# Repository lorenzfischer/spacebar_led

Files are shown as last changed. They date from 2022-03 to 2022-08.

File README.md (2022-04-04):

# Swiss Space Bar LED Installation

> Disclaimer: I am heavily re-using code of an existing project called [Audio Reactive LED Strip](https://github.com/scottlawsonbc/audio-reactive-led-strip)
> by [Scott Lawson](https://github.com/scottlawsonbc). See below for the description of the original project. Please 
> have a read through that, as it explains all of the basics around how to run the python code. I currently only use 
> the "Computer + ESP8266" mode which I have extended to support multiple LED strip clients over a server broadcast
> and client registration (see [client_management.py](python/client_management.py) )

This project aims at developing a hybrid LED system that can be used (i) on a fixed location and (ii) on foot 
when moving around. When multiple LED clients are in the same location, the light show will be sychronised, which 
which should look nice at the bar, on bikes, or when walking around.

The basic idea is to have:

2. a series of LED "things" (LED clients) who are all being fed a light show by a
3. server (either one of the clients or a dedicated server machine)

To keep everything "mobile" we need some wireless communication as well as power from a battery.

There are different modes of operations, currently the following 3 are envisioned:

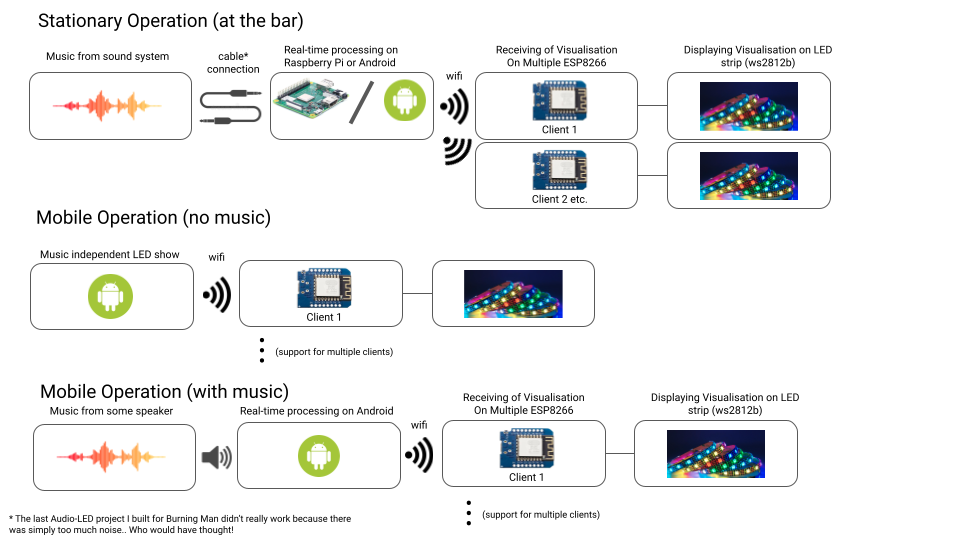
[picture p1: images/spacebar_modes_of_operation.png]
modes of operation


To see whether this is feasible, I have created a demo that is recorded here: https://youtu.be/f2kS4P1rJ0Y
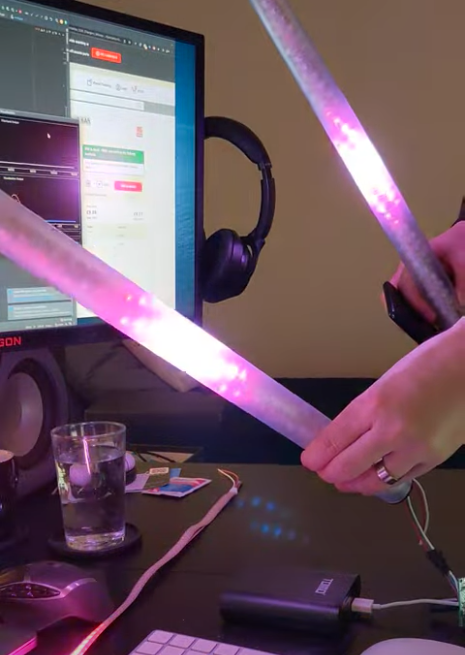
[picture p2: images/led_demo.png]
demo video (https://youtu.be/f2kS4P1rJ0Y)

(click to play)

## ToDo List:

 - [x] Build demo led tube and get others onboard
 - [ ] Brainstorm other/better/larger LED setups (currently we use strips)
   - [ ] Sync with Chef Juke about laser cutting acrylic discs so we could build a tube full of them looking a bit [like this](https://www.youtube.com/watch?v=GtKIkkLkrwU&t=1210s)
 - [ ] Implement different resolutions (currently only 140 LED resolution supported)
 - [ ] Figure out power (battery power)
 - [ ] Figure out charging situation (using charge controller or through removable 18650s?)
 - [ ] Design a handle that can be 3d-printed + easily re-charged overnight
 - [ ] Add status LEDs to circuit and code
 - [ ] Implement dynamic network ports (so we can restart faster) 

## Build of sample tubes

To build the sample tubes, I used ideas that I found in [this video](https://www.youtube.com/watch?v=qnP8-wJVAlI):
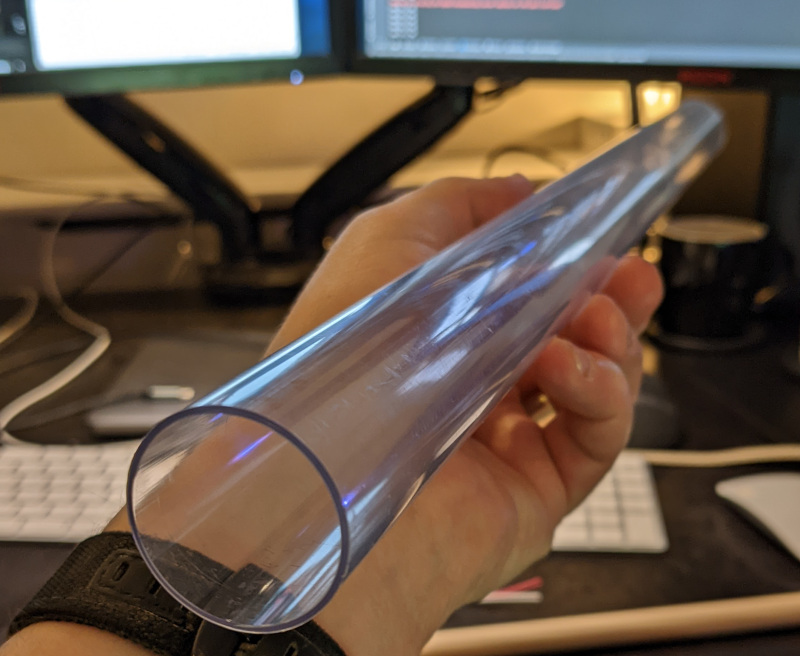
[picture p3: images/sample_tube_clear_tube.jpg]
base tube
1. I used a bunch of acrylic tubes (30mm/32mm inside/outside diameter - clear ones as amazon.co.uk didn't stock anything else) . I sanded them using 600 grit and then 1500 grit sandpaper to get them to diffuse the light.
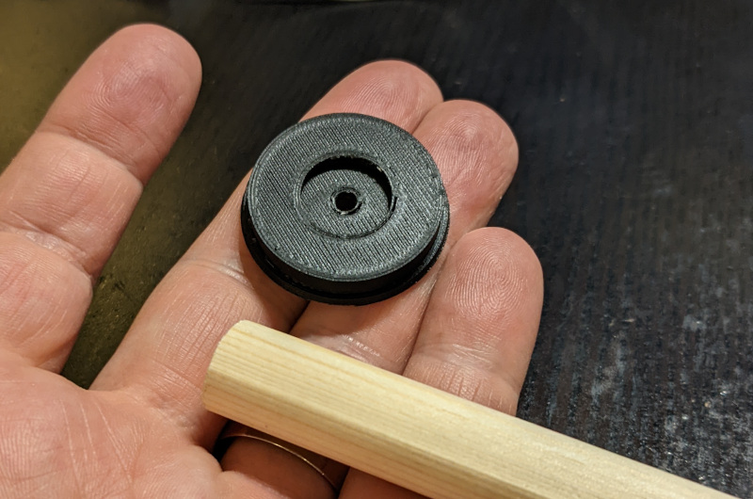
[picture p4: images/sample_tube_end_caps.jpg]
end caps
2. I used 3D printed end caps ([lid.v2.stl](3d_objects/lid.v2.stl) and [lid.v2.with_hole](3d_objects/lid.v2.with_hole.gcode) both in [lid.v2.with_hole.2x.gcode](3d_objects/lid.v2.with_hole.2x.gcode) ready to be printed): 
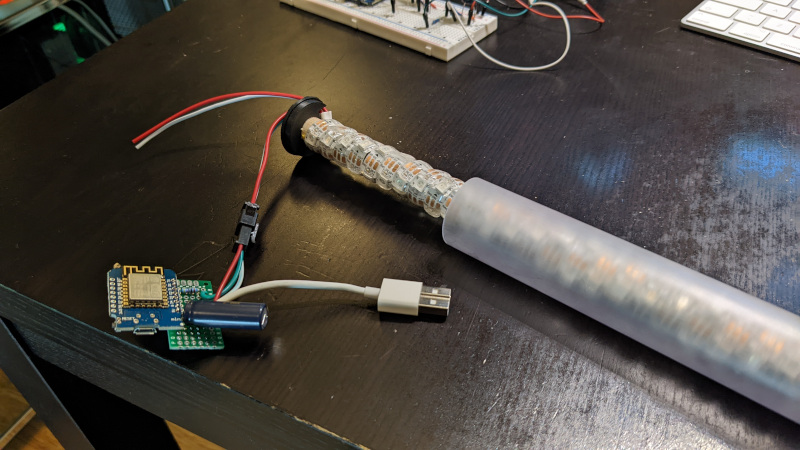
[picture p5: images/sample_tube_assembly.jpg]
tube assembly
3. I then rolled the LED strip around the dowel (superglued each end) and closed the sides (one of the caps has a hole for the cables): 
4. For the circuit I pretty much used the [NeoPixel Wiring Diagram from Adafruit](https://learn.adafruit.com/adafruit-neopixel-uberguide/basic-connections). The only difference that I had is that I used the ESP8266, so the data pin is the RX pin. Currently I power the thing over 5V/Gnd using a USB cable of which I only use the 5V/GND cables (also I didn't have any 1000uF capacitors, so I used 2200uF ones): wiring diagram

## Shopping List
To run one of these tubes you need:
 - a mac or pc running python 3 (2 is not fully supported)
 - a wifi access point in your network
 - (~$5) an ESP8266 (I bought [10 for £25](https://www.amazon.co.uk/gp/product/B08QZ2887K/ref=ppx_yo_dt_b_search_asin_title?ie=UTF8&psc=1))
 - (~$8) an WS2812B LED strip (I used [60 LEDs/m strips from AliExpress](https://www.aliexpress.com/item/4000875413944.html?spm=a2g0o.order_detail.0.0.18b1f19cblbxeD), 5m is enough for two 0.5m tubes)
 - (~5-10) an acrylic/polycarbonate/pet tube (if you find a 30mm/32mm one, you can use the lids from above)
 - a 14mm diameter wooden dowel, same length as the tube (minus 4mm, 2 each side for the cap)
 - two wood screws 3x25mm
 - a 470 Ohms resistor
 - A 1000 uF capacitor

-----

# Original Description: Audio Reactive LED Strip
Real-time LED strip music visualization using Python and the ESP8266 or Raspberry Pi.

block diagram

overview

# Demo (click gif for video)

visualizer demo (https://www.youtube.com/watch?v=HNtM7jH5GXgD)

# Overview
The repository includes everything needed to build an LED strip music visualizer (excluding hardware):

- Python visualization code, which includes code for:
  - Recording audio with a microphone ([microphone.py](python/microphone.py))
  - Digital signal processing ([dsp.py](python/dsp.py))
  - Constructing 1D visualizations ([visualization.py](python/visualization.py))
  - Sending pixel information to the ESP8266 over WiFi ([led.py](python/led.py))
  - Configuration and settings ([config.py](python/config.py))
- Arduino firmware for the ESP8266 ([ws2812_controller_esp8266.ino](arduino/ws2812_controller_esp8266/ws2812_controller_esp8266.ino))

# What do I need to make one?
## Computer + ESP8266
To build a visualizer using a computer and ESP8266, you will need:
- Computer with Python 2.7 or 3.5 ([Anaconda](https://www.anaconda.com/distribution/) is recommended on Windows)
- ESP8266 module with RX1 pin exposed. These modules can be purchased for as little as $5 USD. These modules are known to be compatible, but many others will work too:
  - NodeMCU v3
  - Adafruit HUZZAH
  - Adafruit Feather HUZZAH
- WS2812B LED strip (such as Adafruit Neopixels). These can be purchased for as little as $5-15 USD per meter.
- 5V power supply
- 3.3V-5V level shifter (optional, must be non-inverting)

Limitations when using a computer + ESP8266:
- The communication protocol between the computer and ESP8266 currently supports a maximum of 256 LEDs.

## Standalone Raspberry Pi
You can also build a standalone visualizer using a Raspberry Pi. For this you will need: 
- Raspberry Pi (1, 2, or 3)
- USB audio input device. This could be a USB microphone or a sound card. You just need to find some way of giving the Raspberry Pi audio input.
- WS2812B LED strip (such as Adafruit Neopixels)
- 5V power supply
- 3.3V-5V level shifter (optional)

Limitations when using the Raspberry Pi:
- Raspberry Pi is just fast enough the run the visualization, but it is too slow to run the GUI window as well. It is recommended that you disable the GUI when running the code on the Raspberry Pi.
- The ESP8266 uses a technique called temporal dithering to improve the color depth of the LED strip. Unfortunately the Raspberry Pi lacks this capability.

# Installation for Computer + ESP8266
## Python Dependencies
Visualization code is compatible with Python 2.7 or 3.5. A few Python dependencies must also be installed:
- Numpy
- Scipy (for digital signal processing)
- PyQtGraph (for GUI visualization)
- PyAudio (for recording audio with microphone)

On Windows machines, the use of [Anaconda](https://www.anaconda.com/distribution/) is **highly recommended**. Anaconda simplifies the installation of Python dependencies, which is sometimes difficult on Windows.

### Installing dependencies with Anaconda
Create a [conda virtual environment](http://conda.pydata.org/docs/using/envs.html) (this step is optional but recommended)
```
conda create --name visualization-env python=3.5
activate visualization-env
```
Install dependencies using pip and the conda package manager
```
conda install numpy scipy pyqtgraph
pip install pyaudio
```

### Installing dependencies without Anaconda
The pip package manager can also be used to install the python dependencies.
```
pip install numpy
pip install scipy
pip install pyqtgraph
pip install pyaudio
```
If `pip` is not found try using `python -m pip install` instead.

### Installing macOS dependencies
On macOS, python3 is required and `portaudio` must be used in place of `pyaudio`.
If you don't have brew installed you can get it here: https://brew.sh

```
brew install portaudio
brew install pyqt5
pip3 install numpy
pip3 install scipy
pip3 install pyqtgraph
pip3 install pyaudio
```

Running the visualization can be done using the command below.

`python3 visualization.py /tmp`

## Arduino dependencies
ESP8266 firmare is uploaded using the Arduino IDE. See [this tutorial](https://learn.sparkfun.com/tutorials/esp8266-thing-hookup-guide/installing-the-esp8266-arduino-addon) to setup the Arduino IDE for ESP8266.

### Install NeoPixelBus library
[Download Here](https://github.com/Makuna/NeoPixelBus) or using library manager, search for "NeoPixelBus".

## Hardware Connections
### ESP8266
The ESP8266 has hardware support for [I²S](https://en.wikipedia.org/wiki/I%C2%B2S) and this peripheral is used <!-- by the [ws2812b i2s library](https://github.com/JoDaNl/esp8266_ws2812_i2s)  -->to control the ws2812b LED strip. This significantly improves performance compared to bit-banging the IO pin. Unfortunately, this means that the LED strip **must** be connected to the RX1 pin, which is not accessible in some ESP8266 modules (such as the ESP-01).

The RX1 pin on the ESP8266 module should be connected to the data input pin of the ws2812b LED strip (often labelled DIN or D0).

For the NodeMCU v3 and Adafruit Feather HUZZAH, the location of the RX1 pin is shown in the images below. Many other modules also expose the RX1 pin.

nodemcu-pinout
feather-huzzah-pinout

### Raspberry Pi
Since the Raspberry Pi is a 3.3V device, the best practice is to use a logic level converter to shift the 3.3V logic to 5V logic (WS2812 LEDs use 5V logic). There is a good overview on the [best practices here](https://learn.adafruit.com/adafruit-neopixel-uberguide/best-practices).

Although a logic level converter is the best practice, sometimes it will still work if you simply connect the LED strip directly to the Raspberry Pi.

You cannot power the LED strip using the Raspberry Pi GPIO pins, you need to have an external 5V power supply.

The connections are:

* Connect GND on the power supply to GND on the LED strip and GND on the Raspberry Pi (they MUST share a common GND connection)
* Connect +5V on the power supply to +5V on the LED strip
* Connect a PWM GPIO pin on the Raspberry Pi to the data pin on the LED strip. If using the Raspberry Pi 2 or 3, then try Pin 18(GPIO5).

# Setup and Configuration
1. Install Python and Python dependencies
2. [Install Arduino IDE and ESP8266 addon](https://learn.sparkfun.com/tutorials/esp8266-thing-hookup-guide/installing-the-esp8266-arduino-addon)
3. Download and extract all of the files in this repository onto your computer
4. Connect the RX1 pin of your ESP8266 module to the data input pin of the ws2812b LED strip. Ensure that your LED strip is properly connected to a 5V power supply and that the ESP8266 and LED strip share a common electrical ground connection.
5. In [ws2812_controller.ino](arduino/ws2812_controller/ws2812_controller.ino):
  - Set `const char* ssid` to your router's SSID
  - Set `const char* password` to your router's password
  - Set `IPAddress gateway` to match your router's gateway
  - Set `IPAddress ip` to the IP address that you would like your ESP8266 to use (your choice)
  - Set `#define NUM_LEDS` to the number of LEDs in your LED strip
6. Upload the [ws2812_controller.ino](arduino/ws2812_controller/ws2812_controller.ino) firmware to the ESP8266. Ensure that you have selected the correct ESP8266 board from the boards menu. In the dropdown menu, set `CPU Frequency` to 160 MHz for optimal performance.
7. In [config.py](python/config.py):
  - Set `N_PIXELS` to the number of LEDs in your LED strip (must match `NUM_LEDS` in [ws2812_controller.ino](arduino/ws2812_controller/ws2812_controller.ino))
  - Set `UDP_IP` to the IP address of your ESP8266 (must match `ip` in [ws2812_controller.ino](arduino/ws2812_controller/ws2812_controller.ino))
  - If needed, set `MIC_RATE` to your microphone sampling rate in Hz. Most of the time you will not need to change this.

# Installation for Raspberry Pi
If you encounter any problems running the visualization on a Raspberry Pi, please [open a new issue](https://github.com/scottlawsonbc/audio-reactive-led-strip/issues). Also, please consider opening an issue if you have any questions or suggestions for improving the installation process.

Download and extract all of the files in this repository onto your pi to begin.

## Installing the Python dependencies
Install python dependencies using apt-get
```
sudo apt-get update
sudo apt-get install python-numpy python-scipy python-pyaudio
```

## Audio device configuration
For the Raspberry Pi, a USB audio device needs to be configured as the default audio device.

Create/edit `/etc/asound.conf`
```
sudo nano /etc/asound.conf
```
Set the file to the following text
```
pcm.!default {
    type hw
    card 1
}
ctl.!default {
    type hw
    card 1
}
```

Next, set the USB device to as the default device by editing `/usr/share/alsa/alsa.conf`
```
sudo nano /usr/share/alsa/alsa.conf
```
Change
```
defaults.ctl.card 0
defaults.pcm.card 0
```
To
```
defaults.ctl.card 1
defaults.pcm.card 1
```

## Test the LED strip
1. cd rpi_ws281x/python/examples
2. sudo nano strandtest.py
3. Configure the options at the top of the file. Enable logic inverting if you are using an inverting logic-level converter. Set the correct GPIO pin and number of pixels for the LED strip. You will likely need a logic-level converter to convert the Raspberry Pi's 3.3V logic to the 5V logic used by the ws2812b LED strip.
4. Run example with 'sudo python strandtest.py'

## Configure the visualization code
In `config.py`, set the device to `'pi'` and configure the GPIO, LED and other hardware settings.
If you are using an inverting logic level converter, set `LED_INVERT = True` in `config.py`. Set `LED_INVERT = False` if you are not using an inverting logic level converter (i.e. connecting LED strip directly to GPIO pin).

# Audio Input
The visualization program streams audio from the default audio input device (set by the operating system). Windows users can change the audio input device by [following these instructions](http://blogs.creighton.edu/bluecast/tips-and-tricks/set-the-default-microphone-and-adjust-the-input-volume-in-windows-7/).

Examples of typical audio sources:
* Audio cable connected to the audio input jack (requires USB sound card on Raspberry Pi)
* Webcam microphone, headset, studio recording microphone, etc

## Virtual Audio Source
You can use a "virtual audio device" to transfer audio playback from one application to another. This means that you can play music on your computer and connect the playback directly into the visualization program.

audio-input-sources

### Windows
On Windows, you can use "Stereo Mix" to copy the audio output stream into the audio input. Stereo Mix is only support on certain audio chipsets. If your chipset does not support Stereo Mix, you can use a third-party application such as [Voicemeeter](http://vb-audio.pagesperso-orange.fr/Voicemeeter/).

show-stereomix

Go to recording devices under Windows Sound settings (Control Panel -> Sound). In the right-click menu, select "Show Disabled Devices".

enable-stereomix

Enable Stereo Mix and set it as the default device. Your audio playback should now be used as the audio input source for the visualization program. If your audio chipset does not support Stereo Mix then it will not appear in the list.

### Linux
Linux users can use [Jack Audio](http://jackaudio.org/) to create a virtual audio device.

### OSX
On OSX, [Loopback](https://www.rogueamoeba.com/loopback/) can be use to create a virtual audio device.

# Running the Visualization
Once everything has been configured, run [visualization.py](python/visualization.py) to start the visualization. The visualization will automatically use your default recording device (microphone) as the audio input.

A PyQtGraph GUI will open to display the output of the visualization on the computer. There is a setting to enable/disable the GUI display in [config.py](python/config.py)

visualization-gui

If you encounter any issues or have questions about this project, feel free to [open a new issue](https://github.com/scottlawsonbc/audio-reactive-led-strip/issues).

# Limitations
* ESP8266 supports a maximum of 256 LEDs. This limitation will be removed in a future update. The Raspberry Pi can use more than 256 LEDs.
* Even numbers of pixels must be used. For example, if you have 71 pixels then use the next lowest even number, 70. Odd pixel quantities will be supported in a future update.

# License
This project was developed by Scott Lawson and is released under the MIT License.

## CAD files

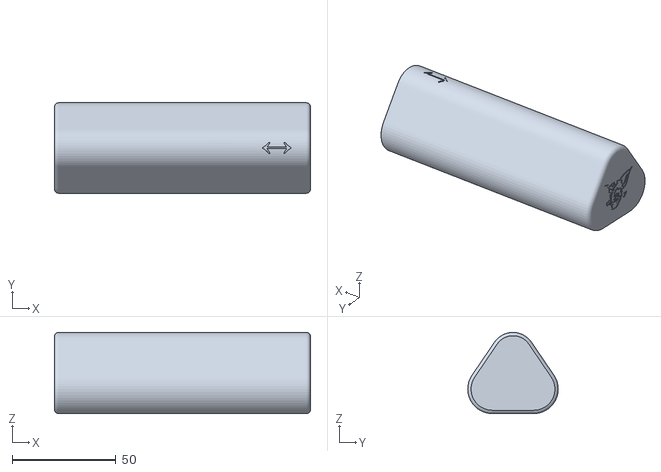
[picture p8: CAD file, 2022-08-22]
3d_objects/cover.v2.0_25mm.stl
123.6 x 43.7 x 39.2

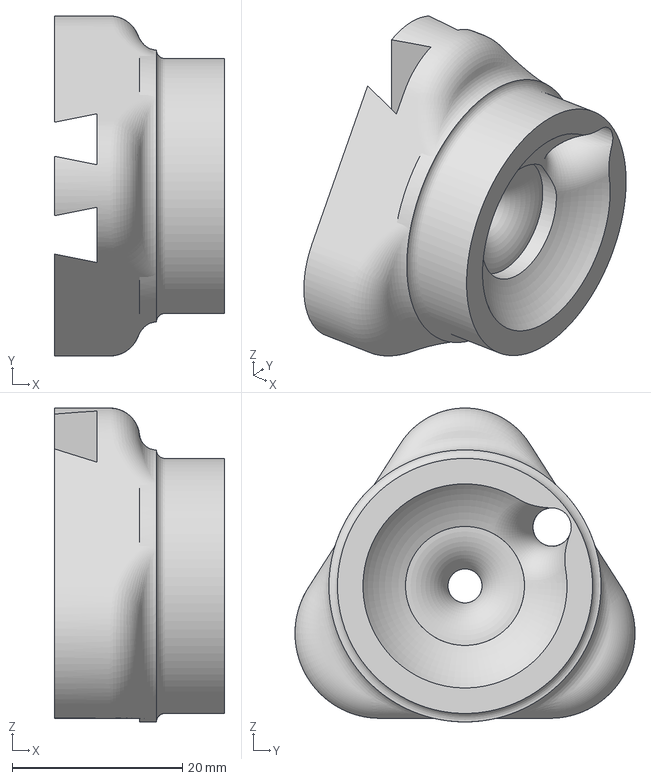
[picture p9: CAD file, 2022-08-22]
3d_objects/head.v5.hole_left.3mf
20.0 x 40.0 x 36.9 mm

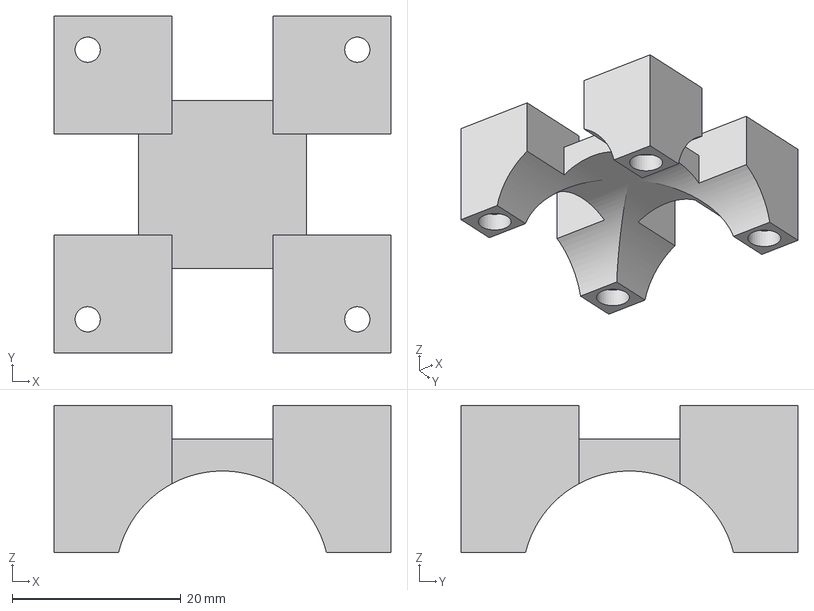
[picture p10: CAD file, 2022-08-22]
3d_objects/holder.pole_bracket.v2.thick_reversed.3mf
40.0 x 40.0 x 17.5 mm

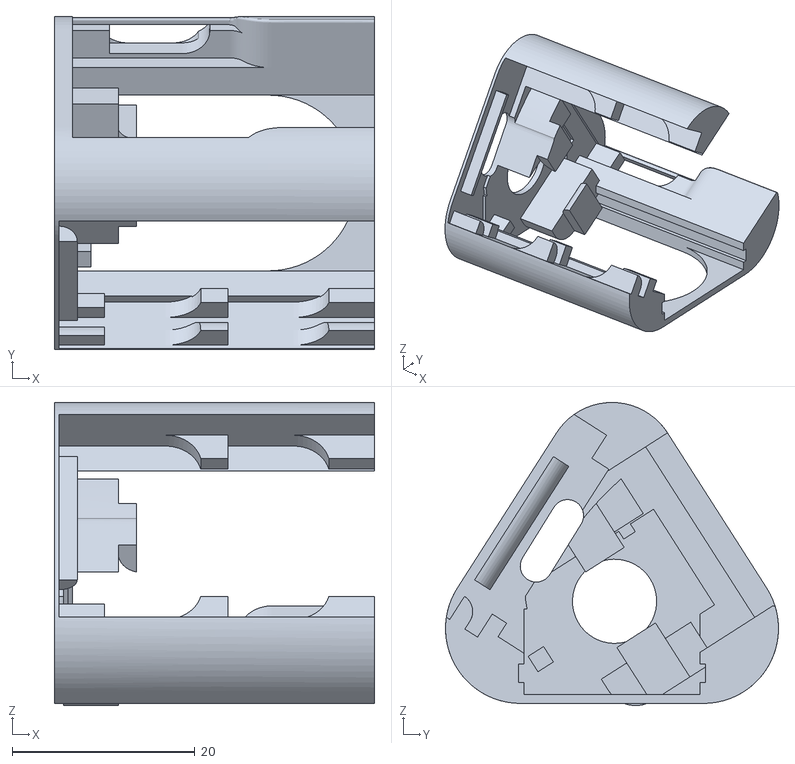
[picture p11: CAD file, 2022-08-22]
3d_objects/electronics_platform.v14.tp4056_2.stl
35.0 x 36.4 x 33.1

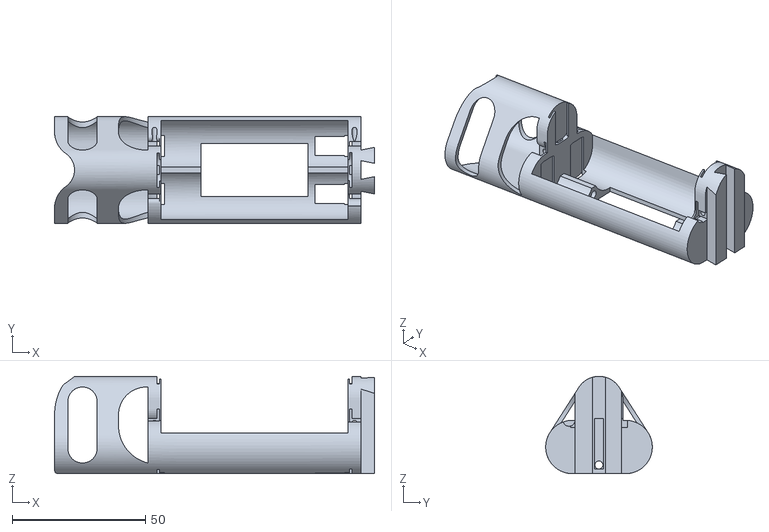
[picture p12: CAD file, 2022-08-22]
3d_objects/battery_holder.v13.18_5mm.stl
120.0 x 40.0 x 36.5

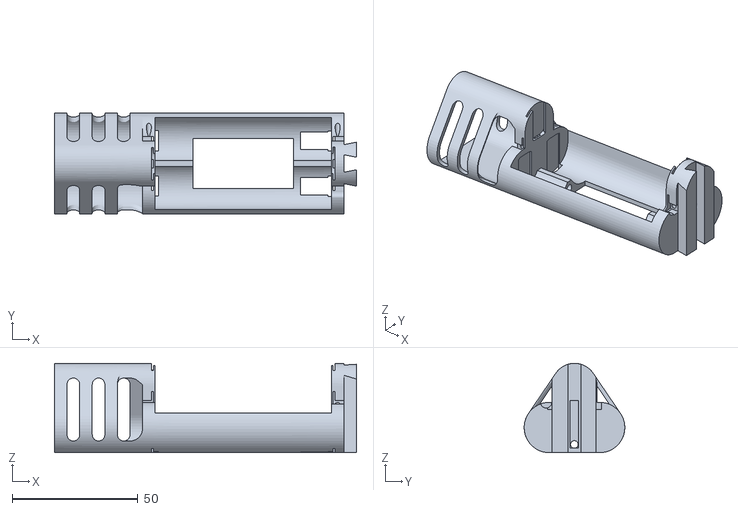
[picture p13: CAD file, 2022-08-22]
3d_objects/battery_holder.v11.18_2mm.stl
120.0 x 40.0 x 35.5

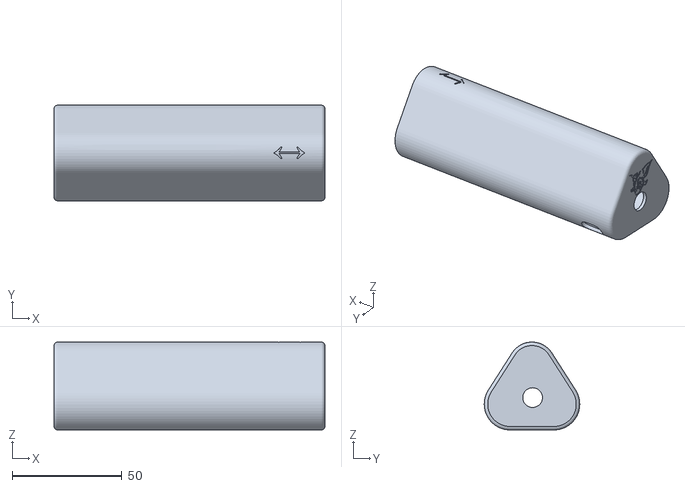
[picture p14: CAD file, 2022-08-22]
3d_objects/cover.v5.chargerhole_05.stl
123.6 x 43.6 x 40.1

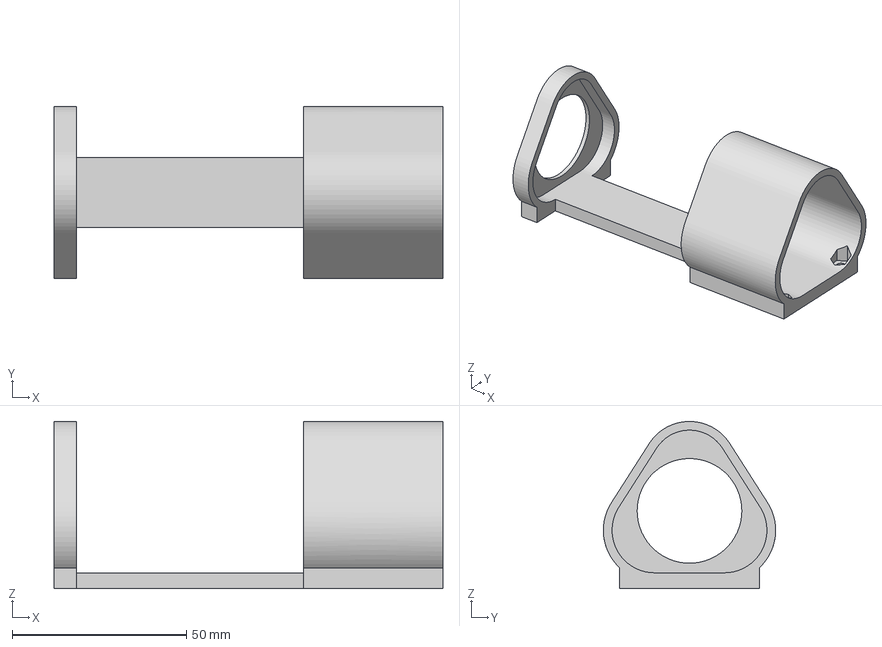
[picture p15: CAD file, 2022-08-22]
3d_objects/holder.cup.v2.thick_reversed.3mf
111.5 x 49.4 x 47.9 mm

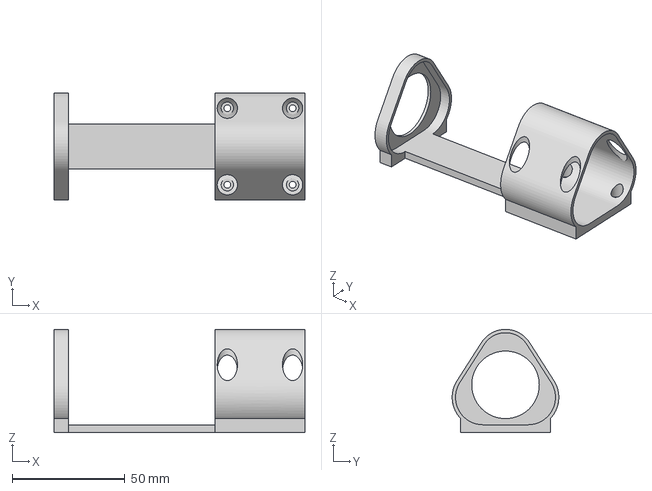
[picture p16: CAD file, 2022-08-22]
3d_objects/holder.cup..v1.3mf
111.5 x 47.4 x 45.9 mm

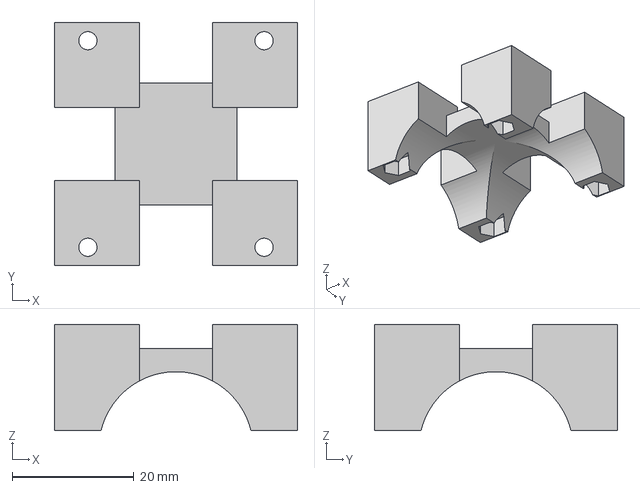
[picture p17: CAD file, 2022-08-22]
3d_objects/holder.pole_bracket.v1.3mf
40.0 x 40.0 x 17.5 mm

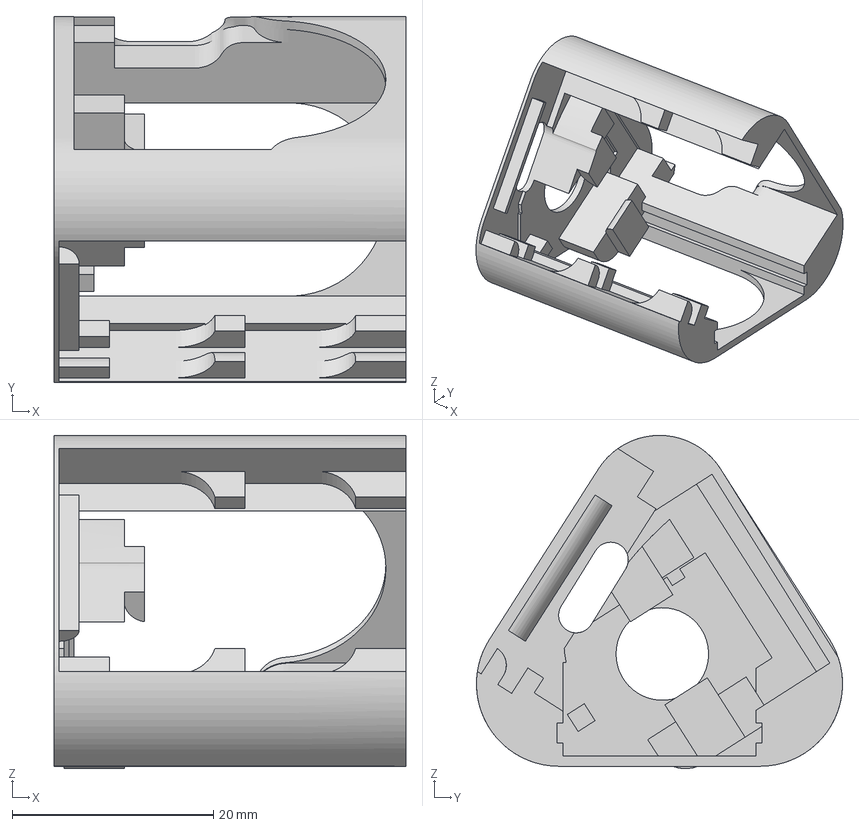
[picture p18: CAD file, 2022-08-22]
3d_objects/electronics_platform.v16.tp4056_stabiliser.3mf
35.0 x 36.4 x 33.1 mm

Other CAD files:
3d_objects/electronics_platform.v15.chargerhole_05.stl
3d_objects/head.v4.16_5mm.stl
3d_objects/battery_holder.v15.chargerhole_05.stl
3d_objects/battery_holder.v14.charger_cutout.stl
3d_objects/battery_holder.v17.hole_left.3mf
3d_objects/head.v6.lower.3mf
3d_objects/battery_holder.v18.lower.3mf
3d_objects/battery_holder.v12.16_5mm.stl
3d_objects/cover.v3.0_2mm.stl
3d_objects/cover.v4.charger_button.stl
3d_objects/electronics_platform.v1.stl
3d_objects/electronics_platform.v10.stl
3d_objects/electronics_platform.v11.stl
3d_objects/electronics_platform.v12.stl
3d_objects/electronics_platform.v13.tp4056.stl
3d_objects/electronics_platform.v2.stl
3d_objects/electronics_platform.v3.stl
3d_objects/electronics_platform.v4.stl
3d_objects/electronics_platform.v5.stl
3d_objects/electronics_platform.v6.stl
3d_objects/electronics_platform.v7.stl
3d_objects/electronics_platform.v8.stl
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

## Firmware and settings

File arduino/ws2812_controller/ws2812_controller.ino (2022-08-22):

/*
* This example works for ESP8266 & ESP32 and uses the NeoPixelBus library instead of the one bundle
* Sketch written by Joey Babcock - https://joeybabcock.me/blog/, and Scott Lawson (Below) 
* Codebase created by ScottLawsonBC - https://github.com/scottlawsonbc
*/
#include <NeoPixelBus.h>
#include <NeoPixelAnimator.h>
#include <math.h>  // we need this to get M_PI

#if defined(ESP8266)
#include <ESP8266WiFi.h>
#include <WiFiUdp.h>
#elif defined(ESP32)
#include <WiFi.h>
#else
#error "This is not a ESP8266 or ESP32!"
#endif

// Wifi and socket settings
const char* ssid     = "WIFI_SSID";  // your (2.4GHz) WiFi SSID
const char* password = "WIFI_PW";  // your WiFi password

// Set to the number of LEDs in your LED strip
#define NUM_LEDS 140
// Maximum number of packets to hold in the buffer. Don't change this.
#define BUFFER_LEN 1024
// Toggles FPS output (1 = print FPS over serial, 0 = disable output)
#define PRINT_FPS 1
#define NUM_ANIMATION_CHANNELS 3 // 1=battery, 2=network, 3=not defined yet
#define ANIMATION_CHANNEL_BATTERY 0
#define ANIMATION_CHANNEL_NETWORK 1
#define ANIMATION_SECONDS_BATTERY 2 // we want the battery animation to take 2 seconds
#define ANIMATION_SECONDS_NETWORK 10 // we want the network animation to run for at most 10 seconds
#define BATTERY_UPDATE_INTERVAL_SECONDS 10  // we only update the battery level every 10 seconds
#define SERVER_TIMEOUT_SECONDS 10  // wait for 10 seconds before trying to reconnect

//NeoPixelBus settings
const uint8_t PixelPin = 4;  // make sure to set this to the correct pin, ignored for Esp8266, which will use the RX pin (set to 3 by default for DMA)
const RgbColor COLOR_OFF = RgbColor(0,0,0);

unsigned int localPort = 7777;
IPAddress multicastIp(224, 1, 1, 1);  // hard coded 
unsigned int multicastPort = 5555;
unsigned int serverPort = 1337;  // hard coded for now todo: make dynamic
char packetBuffer[BUFFER_LEN];

uint8_t N = 0;

//// Network information
//IPAddress ip(192, 168, 1, 200);  // IP must match the IP in config.py
//IPAddress gateway(192, 168, 1, 1);  // Set gateway to your router's gateway
//IPAddress subnet(255, 255, 255, 0);

WiFiUDP port;
NeoPixelBus<NeoGrbFeature, Neo800KbpsMethod> ledstrip(NUM_LEDS, PixelPin);
NeoPixelAnimator animations(NUM_ANIMATION_CHANNELS); // NeoPixel animation management object, with 
uint8_t _numberOfZeroPacketReceipts = 0;
long _lastPacketReceived;  // detect when we lose the connection to the server
float _batteryLevel;  // we store the current battery level in this
long _lastBatteryUpdateMillis = millis();  // store when we last updated the battery

#if PRINT_FPS
    uint16_t fpsCounter = 0;
    uint32_t secondTimer = 0;
#endif


/** turns all LEDs on the strip off. */
void clearStrip() {
  ledstrip.ClearTo(COLOR_OFF);
  ledstrip.Show();
}


/** 
 *  This method registers this led client with the server, so it will receive led show data packets going forward.
 *  
 *  It works in two steps:
 *  
 *   1. wait for a server broadcast announcing the server IP
 *   2. send this clients IP to the server, asking for show data packets to be sent to us
 *  
 */
void registerWithServer() {
  IPAddress serverIp = NULL;
  WiFiClient client;
  WiFiUDP mcast;
  char packet[BUFFER_LEN];
  int packetSize;

  // turn off all the LEDs while we're doing this
  clearStrip();
  
  Serial.print("Listening for server broadcast ");
  mcast.beginMulticast(WiFi.localIP(), multicastIp, multicastPort);
  for (int i=0; i<20 && !serverIp; i++) {
    packetSize = mcast.parsePacket();
    if (packetSize > 0) {
      int len = mcast.read(packet, BUFFER_LEN);
      packet[len] = '\0';  // 0-terminate the string, so we know where to stop reading
      serverIp = IPAddress((uint8_t)packet[0], (uint8_t)packet[1], (uint8_t)packet[2], (uint8_t)packet[3]);
    } else {
      delay(500);  
      Serial.print(".");
    }
  }
  mcast.stop();

  if (!serverIp) {
    Serial.print(" no server found!");
  } else {
    Serial.print(" server found at ");
    Serial.println(serverIp);
  
    Serial.print("Registering with server at ");
    Serial.print(serverIp);
    Serial.print(":");
    Serial.print(serverPort);
    Serial.print(" ... ");
    if (!client.connect(serverIp, serverPort)) {
      Serial.println(" connection failed");
      delay(500);
    } else {  // connection to server established
      client.write((uint8_t*) &localPort,sizeof(localPort)); // the server will see our ip, so we only have to tell it the port we're listing on
      client.stop();
      Serial.println(" client registered!");
    }
  }

  _lastPacketReceived = millis();  // only try to connect to the server once a second
}


#define READ_AT_42V 898.0  // this is what I read as the A0 value at 4.2V input (max voltage for 18650 cells)
#define READ_AT_3V 642.0  // this is what I read as the A0 value at 3.0V input (min voltage for 18650 cells)
/** This method probes the A0 (analog 0 pin) to find the current battery level.*/
float measureBatteryLevel() {
  int nVoltageRaw = analogRead(A0);
  float batteryLevelNorm = ((float) nVoltageRaw - READ_AT_3V) / (READ_AT_42V - READ_AT_3V);
  return max(min(batteryLevelNorm, 1.0f), 0.0f);
}


/** Updates the battery level at a fixed interval and returns the last measured battery level. */
float updateAndGetBatteryLevel() {
  if ((_batteryLevel == NULL) || 
      (_lastBatteryUpdateMillis + (BATTERY_UPDATE_INTERVAL_SECONDS * 1000) < millis())
  ){
    //Serial.println("updating battery");
    _batteryLevel = measureBatteryLevel();
    _lastBatteryUpdateMillis = millis();
  }
  return _batteryLevel;
}


void batteryStatusAnimationUpdate(const AnimationParam& param) {
  // we fake a progress that's twice the actual progress, so the battery level can be seen half of the time
  float fakeProgress = 2 * param.progress;  
  //  Serial.println(param.progress);
  
  if (param.state == AnimationState_Completed) {
      playNetworkStatusAnimation();
      clearStrip();
  } else {
    if (fakeProgress < 1.0) {
      /*
       * We want the green leds to move up and down 3 times and then at the third round, 
       * stop at the current battery level. We use a sign wave for this
       */
      int fullAnimation = 360 + (updateAndGetBatteryLevel() * 180);  // we do two full waves and then stop at the charge level
      float angle = ((fakeProgress * fullAnimation) - 90) * (M_PI / 180);  // -90 => start at the bottom of the sine wave
      float wave = sin(angle);  // this will be a value between -1 and 1, we need it between 0 and 1 ...
      float waveNorm = (wave + 1) / 2;  // .. so we normalise it here
      float pixelsOn = waveNorm * NUM_LEDS;  // ... and finally multiply with the number of LEDs we have
  
      for (int p=0; p<NUM_LEDS; p++) {  // the pixel index
        if (p < pixelsOn) {
          ledstrip.SetPixelColor(p, RgbColor(0, 255, 0));  // green
        } else {
          ledstrip.SetPixelColor(p, COLOR_OFF);  
        }
      }  
    }
  }
}


/** This measures the battery level and plays an animation on the strip to show the battery level. */
void playBatteryAnimation() {
  clearStrip(); // turn all LEDs off, so we get a clean battery reading  

  Serial.printf("Battery Level (BAT): %d%%\n", (int) round(updateAndGetBatteryLevel() * 100));
  animations.StartAnimation(
    ANIMATION_CHANNEL_BATTERY,
    ANIMATION_SECONDS_BATTERY * 1000,
    batteryStatusAnimationUpdate
  );
}


void connectToWifi() {
  Serial.println("");
  Serial.printf("Connecting to %s ...\n", ssid);
  WiFi.mode(WIFI_STA);
  //WiFi.config(ip, gateway, subnet);  // uncomment this to override DHCP
  WiFi.begin(ssid, password);  // we use DHCP for the ip configuration
}


/**Renders an animation while the network is still connecting. */
void networkStatusUpdate(const AnimationParam& param) {
    if (!animations.IsAnimationActive(ANIMATION_CHANNEL_NETWORK)) { // after we stopped the animation, stop coming in here
      return;
    }
    // Serial.println(param.progress);

    int fullAnimation = 10 * 360; // we want the white leds to move up and down 10 times, at most
    float angle = ((param.progress * fullAnimation) - 90) * (M_PI / 180);  // -90 => start at the bottom of the sine wave
    float wave = sin(angle);  // this will be a value between -1 and 1, we need it between 0 and 1 ...
    float waveNorm = (wave + 1) / 2;  // .. so we normalise it here
    float pixelsOn = waveNorm * NUM_LEDS;  // ... and finally multiply with the number of LEDs we have

    for (int p=0; p<NUM_LEDS; p++) {  // the pixel index
      if (p < pixelsOn) {
        ledstrip.SetPixelColor(p, RgbColor(255, 255, 255));  // white
      } else {
        ledstrip.SetPixelColor(p, COLOR_OFF);  
      }
    }  
    
    if (WiFi.status() == WL_CONNECTED) {
      Serial.println("");
      Serial.printf("Connected to %s\n", ssid);
      Serial.print("IP address: ");
      Serial.println(WiFi.localIP());
      animations.StopAnimation(ANIMATION_CHANNEL_NETWORK);
      animations.Pause(); // stop all animations
      clearStrip();
    }
}


/** This will play the network status animation */
void playNetworkStatusAnimation() {
  animations.Resume(); // in case the animation framework was paused
  if (!animations.IsAnimationActive(ANIMATION_CHANNEL_NETWORK)) {
    animations.StartAnimation(
      ANIMATION_CHANNEL_NETWORK,
      ANIMATION_SECONDS_NETWORK * 1000,
      networkStatusUpdate
    );
  }
}


/** checks whether we have a connection to an LED server. */
bool connectedToServer() {
  // if we haven't received anything from the server for more than 2 seconds ..
  return (millis() - _lastPacketReceived) < (SERVER_TIMEOUT_SECONDS * 1000); 
}


void setup() {
    Serial.begin(115200);

    ledstrip.Begin();//Begin output
    ledstrip.Show();//Clear the strip for use

    connectToWifi();
        
    // start listening for messages from the server
    port.begin(localPort);
    _lastPacketReceived = millis() - (SERVER_TIMEOUT_SECONDS * 1000); // start the count
    
    playBatteryAnimation();  // measure battery level and display on the stip
}


void loop() {
    updateAndGetBatteryLevel();
    
    if (!animations.IsPaused()) {
      
      animations.UpdateAnimations();
        
    } else {  // if the animator is paused, play the instructions received from the server

      // Read data over socket
      int packetSize = port.parsePacket();
      
      if (packetSize == 0) {
        _numberOfZeroPacketReceipts++;
        /* 
         * TODO: 
         * 
         * Move all the connection code into one method which will be called in reach update. This method will 
         * then check if the wifi is up and if we are receiving server messages. if either is not the case
         * it will initiate the wifi connection, and listen for the server broadcast and if we are receiving
         * messages.
         * 
         * Only if we are, will we stop the connection animation. If we don't hear from the server withing 10 seconds
         * we start some random animation
         * 
         */
        
        if (!connectedToServer()) {
          registerWithServer();  
        } else { // if we are connected to the server, but still didn't receive any packets
          if (_numberOfZeroPacketReceipts >= 2) {
            delay(_numberOfZeroPacketReceipts * 10);  
            Serial.printf(".");
          }
        }
        
      } else {  // If packets have been received, interpret the command
          _numberOfZeroPacketReceipts = 0; 
          _lastPacketReceived = millis();
          int len = port.read(packetBuffer, BUFFER_LEN);
          packetBuffer[len] = 0;  // what is this for?
          for(int i = 0; i < len; i+=4) {
              N = packetBuffer[i];
              RgbColor pixel((uint8_t)packetBuffer[i+1], (uint8_t)packetBuffer[i+2], (uint8_t)packetBuffer[i+3]);//color
              ledstrip.SetPixelColor(N, pixel);//N is the pixel number
          } 
          #if PRINT_FPS
              fpsCounter++;
              Serial.print("/");//Monitors connection(shows jumps/jitters in packets)
          #endif
          
      }
      #if PRINT_FPS
          if (millis() - secondTimer >= 1000U) {
              secondTimer = millis();
              Serial.printf("FPS: %d BAT: %d%% \n", fpsCounter, (int) round(_batteryLevel * 100));
              fpsCounter = 0;
          }   
      #endif
      
    }
    ledstrip.Show();
}

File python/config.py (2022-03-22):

"""Settings for audio reactive LED strip"""
from __future__ import print_function
from __future__ import division
import os

DEVICE = 'esp8266'
#DEVICE = 'pi'
"""Device used to control LED strip. Must be 'pi',  'esp8266' or 'blinkstick'

'esp8266' means that you are using an ESP8266 module to control the LED strip
and commands will be sent to the ESP8266 over WiFi.

'pi' means that you are using a Raspberry Pi as a standalone unit to process
audio input and control the LED strip directly.

'blinkstick' means that a BlinkstickPro is connected to this PC which will be used
to control the leds connected to it.
"""

if DEVICE == 'esp8266':
    SOFTWARE_GAMMA_CORRECTION = False
    """Set to False because the firmware handles gamma correction + dither"""
    MULTICAST_TTL = 1
    """for all packets sent, after two hops on the network the packet will not 
    be re-sent/broadcast (see https://www.tldp.org/HOWTO/Multicast-HOWTO-6.html)"""
    MCAST_GRP = '224.1.1.1'
    """multicast group ip"""
    MCAST_PORT = 5555
    """multicast port"""
    SERVER_PORT = 1337
    """the port at which the server receives registrations"""

if DEVICE == 'pi':
    LED_PIN = 18
    """GPIO pin connected to the LED strip pixels (must support PWM)"""
    LED_FREQ_HZ = 800000
    """LED signal frequency in Hz (usually 800kHz)"""
    LED_DMA = 5
    """DMA channel used for generating PWM signal (try 5)"""
    BRIGHTNESS = 255
    """Brightness of LED strip between 0 and 255"""
    LED_INVERT = True
    """Set True if using an inverting logic level converter"""
    SOFTWARE_GAMMA_CORRECTION = True
    """Set to True because Raspberry Pi doesn't use hardware dithering"""

if DEVICE == 'blinkstick':
    SOFTWARE_GAMMA_CORRECTION = True
    """Set to True because blinkstick doesn't use hardware dithering"""

USE_GUI = True
"""Whether or not to display a PyQtGraph GUI plot of visualization"""

DISPLAY_FPS = True
"""Whether to display the FPS when running (can reduce performance)"""

N_PIXELS = 140
"""Number of pixels in the LED strip (must match ESP8266 firmware)"""

GAMMA_TABLE_PATH = os.path.join(os.path.dirname(__file__), 'gamma_table.npy')
"""Location of the gamma correction table"""

MIC_RATE = 44100
"""Sampling frequency of the microphone in Hz"""

FPS = 70
"""Desired refresh rate of the visualization (frames per second)

FPS indicates the desired refresh rate, or frames-per-second, of the audio
visualization. The actual refresh rate may be lower if the computer cannot keep
up with desired FPS value.

Higher framerates improve "responsiveness" and reduce the latency of the
visualization but are more computationally expensive.

Low framerates are less computationally expensive, but the visualization may
appear "sluggish" or out of sync with the audio being played if it is too low.

The FPS should not exceed the maximum refresh rate of the LED strip, which
depends on how long the LED strip is.
"""
_max_led_FPS = int(((N_PIXELS * 30e-6) + 50e-6)**-1.0)
assert FPS <= _max_led_FPS, 'FPS must be <= {}'.format(_max_led_FPS)

MIN_FREQUENCY = 200
"""Frequencies below this value will be removed during audio processing"""

MAX_FREQUENCY = 12000
"""Frequencies above this value will be removed during audio processing"""

N_FFT_BINS = 24
"""Number of frequency bins to use when transforming audio to frequency domain

Fast Fourier transforms are used to transform time-domain audio data to the
frequency domain. The frequencies present in the audio signal are assigned
to their respective frequency bins. This value indicates the number of
frequency bins to use.

A small number of bins reduces the frequency resolution of the visualization
but improves amplitude resolution. The opposite is true when using a large
number of bins. More bins is not always better!

There is no point using more bins than there are pixels on the LED strip.
"""

N_ROLLING_HISTORY = 2
"""Number of past audio frames to include in the rolling window"""

MIN_VOLUME_THRESHOLD = 1e-7
"""No music visualization displayed if recorded audio volume below threshold"""

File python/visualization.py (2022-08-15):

from __future__ import print_function
from __future__ import division
import time
import numpy as np
from scipy.ndimage.filters import gaussian_filter1d
import client_management
import config
import logging
import microphone
import dsp
import led

# setup logging
logging.basicConfig(level=logging.DEBUG,
                    format='%(asctime)s %(levelname)s %(message)s')

_time_prev = time.time() * 1000.0
"""The previous time that the frames_per_second() function was called"""

_fps = dsp.ExpFilter(val=config.FPS, alpha_decay=0.2, alpha_rise=0.2)
"""The low-pass filter used to estimate frames-per-second"""

_clients = {}
"""This is the dictionary where we keep all ip:port combinations that we need to send data to.
    
    { ip_address_as_string: port_as_int, ... }
"""

def frames_per_second():
    """Return the estimated frames per second

    Returns the current estimate for frames-per-second (FPS).
    FPS is estimated by measured the amount of time that has elapsed since
    this function was previously called. The FPS estimate is low-pass filtered
    to reduce noise.

    This function is intended to be called one time for every iteration of
    the program's main loop.

    Returns
    -------
    fps : float
        Estimated frames-per-second. This value is low-pass filtered
        to reduce noise.
    """
    global _time_prev, _fps
    time_now = time.time() * 1000.0
    dt = time_now - _time_prev
    _time_prev = time_now
    if dt == 0.0:
        return _fps.value
    return _fps.update(1000.0 / dt)


def memoize(function):
    """Provides a decorator for memoizing functions"""
    from functools import wraps
    memo = {}

    @wraps(function)
    def wrapper(*args):
        if args in memo:
            return memo[args]
        else:
            rv = function(*args)
            memo[args] = rv
            return rv
    return wrapper


@memoize
def _normalized_linspace(size):
    return np.linspace(0, 1, size)


def interpolate(y, new_length):
    """Intelligently resizes the array by linearly interpolating the values

    Parameters
    ----------
    y : np.array
        Array that should be resized

    new_length : int
        The length of the new interpolated array

    Returns
    -------
    z : np.array
        New array with length of new_length that contains the interpolated
        values of y.
    """
    if len(y) == new_length:
        return y
    x_old = _normalized_linspace(len(y))
    x_new = _normalized_linspace(new_length)
    z = np.interp(x_new, x_old, y)
    return z


r_filt = dsp.ExpFilter(np.tile(0.01, config.N_PIXELS // 2),
                       alpha_decay=0.2, alpha_rise=0.99)
g_filt = dsp.ExpFilter(np.tile(0.01, config.N_PIXELS // 2),
                       alpha_decay=0.05, alpha_rise=0.3)
b_filt = dsp.ExpFilter(np.tile(0.01, config.N_PIXELS // 2),
                       alpha_decay=0.1, alpha_rise=0.5)
common_mode = dsp.ExpFilter(np.tile(0.01, config.N_PIXELS // 2),
                       alpha_decay=0.99, alpha_rise=0.01)
p_filt = dsp.ExpFilter(np.tile(1, (3, config.N_PIXELS // 2)),
                       alpha_decay=0.1, alpha_rise=0.99)
p = np.tile(1.0, (3, config.N_PIXELS // 2))
gain = dsp.ExpFilter(np.tile(0.01, config.N_FFT_BINS),
                     alpha_decay=0.001, alpha_rise=0.99)


def visualize_scroll(y):
    """Effect that originates in the center and scrolls outwards"""
    global p
    y = y**2.0
    gain.update(y)
    y /= gain.value
    y *= 255.0
    r = int(np.max(y[:len(y) // 3]))
    g = int(np.max(y[len(y) // 3: 2 * len(y) // 3]))
    b = int(np.max(y[2 * len(y) // 3:]))
    # Scrolling effect window
    p[:, 1:] = p[:, :-1]
    p *= 0.98
    p = gaussian_filter1d(p, sigma=0.2)
    # Create new color originating at the center
    p[0, 0] = r
    p[1, 0] = g
    p[2, 0] = b
    # Update the LED strip
    return np.concatenate((p[:, ::-1], p), axis=1)


def visualize_energy(y):
    """Effect that expands from the center with increasing sound energy"""
    global p
    y = np.copy(y)
    gain.update(y)
    y /= gain.value
    # Scale by the width of the LED strip
    y *= float((config.N_PIXELS // 2) - 1)
    # Map color channels according to energy in the different freq bands
    scale = 0.9
    r = int(np.mean(y[:len(y) // 3]**scale))
    g = int(np.mean(y[len(y) // 3: 2 * len(y) // 3]**scale))
    b = int(np.mean(y[2 * len(y) // 3:]**scale))
    # Assign color to different frequency regions
    p[0, :r] = 255.0
    p[0, r:] = 0.0
    p[1, :g] = 255.0
    p[1, g:] = 0.0
    p[2, :b] = 255.0
    p[2, b:] = 0.0
    p_filt.update(p)
    p = np.round(p_filt.value)
    # Apply substantial blur to smooth the edges
    p[0, :] = gaussian_filter1d(p[0, :], sigma=4.0)
    p[1, :] = gaussian_filter1d(p[1, :], sigma=4.0)
    p[2, :] = gaussian_filter1d(p[2, :], sigma=4.0)
    # Set the new pixel value
    return np.concatenate((p[:, ::-1], p), axis=1)


_prev_spectrum = np.tile(0.01, config.N_PIXELS // 2)


def visualize_spectrum(y):
    """Effect that maps the Mel filterbank frequencies onto the LED strip"""
    global _prev_spectrum
    y = np.copy(interpolate(y, config.N_PIXELS // 2))
    common_mode.update(y)
    diff = y - _prev_spectrum
    _prev_spectrum = np.copy(y)
    # Color channel mappings
    r = r_filt.update(y - common_mode.value)
    g = np.abs(diff)
    b = b_filt.update(np.copy(y))
    # Mirror the color channels for symmetric output
    r = np.concatenate((r[::-1], r))
    g = np.concatenate((g[::-1], g))
    b = np.concatenate((b[::-1], b))
    output = np.array([r, g,b]) * 255
    return output


fft_plot_filter = dsp.ExpFilter(np.tile(1e-1, config.N_FFT_BINS),
                         alpha_decay=0.5, alpha_rise=0.99)
mel_gain = dsp.ExpFilter(np.tile(1e-1, config.N_FFT_BINS),
                         alpha_decay=0.01, alpha_rise=0.99)
mel_smoothing = dsp.ExpFilter(np.tile(1e-1, config.N_FFT_BINS),
                         alpha_decay=0.5, alpha_rise=0.99)
volume = dsp.ExpFilter(config.MIN_VOLUME_THRESHOLD,
                       alpha_decay=0.02, alpha_rise=0.02)
fft_window = np.hamming(int(config.MIC_RATE / config.FPS) * config.N_ROLLING_HISTORY)
prev_fps_update = time.time()
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

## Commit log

2022-03-22 adding 3d printed end caps
    [lid.v2.stl, lid.v2.with_hole.stl]
2022-03-22 added tester that allows testing of led strips
2022-03-22 quick commit, might have missed stuff
    [client_management.py, config.py, led.py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]
2022-03-22 adding info on dowel and screws
2022-04-04 added super simple battery level measurement + animation. needs more work, but it shows the battery level
2022-08-15 removed port addition, as this didn't work on the arduino side
    [client_management.py]
2022-08-15 only delaying if there are multiple missed packets, this removed quite a bit of jitter
    [ws2812_controller.ino]
2022-08-15 removing the LedValue class, as we now use matrices
2022-08-15 make the gain normalisation per fft bucket, this leads to less of a dominance of high frequencies
2022-08-22 adding all 3d files
    [battery_holder.v11.18_2mm.stl, battery_holder.v12.16_5mm.stl, battery_holder.v13.18_5mm.stl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]
2023-04-13 Trying to fix the issue that one can't dance long enough as phone goes to sleep mode... + small cleanup
    Set of changes:
    - BatteryDrainer introduced, hopefully it's gonna fix your problem. Let me know & see comments inside.
    - This should also allow you to remove the different hacks, like setting thread priorities... Fingers crossed
    - Layout fixed... Sorry, couldn't look at it without crying... ;)
    - Removed not needed permissions (FOREGROUND_SERVICE) as duplicated, and you already have it
    - Introduced new permission WAKE_LOCK, as needed for WAKE_LOCK proposed solution
    Test and let me know
